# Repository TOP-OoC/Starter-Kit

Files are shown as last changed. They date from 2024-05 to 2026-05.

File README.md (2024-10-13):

# Starter-Kit

## Description
The TOP Starter Kit is an open-source, reconfigurable platform for Organ on Chip (OoC) research. It implements a Fluidic Circuit Board (FCB) architecture, meaning that Microfluidic Building Blocks (MFBBs) are the functional units and fluids are routed between MFBBs via a single manifold, the FCB.

The specific FCB used in the Stater Kit is designed to allow arbitrary connections between microfluidic modules. Interconnections can be easily changed to whatever the user desires by simply exchanging a single MFBB called the Routing Block. 

Microfluidic building block port layouts and footprints follow our [TOP Design Rules (TDRs)](https://data.4tu.nl/datasets/2558bd4c-d7ad-4e17-bc54-8c335b4c1c01) which are compliant with [ISO 22916:2022](https://www.iso.org/standard/74157.html) (See also: [a short introduction to ISO:22916:2022](https://data.4tu.nl/datasets/871d6c3a-cf1a-44f9-865a-6da842bd2f27/2)).

Taking all of it's features together, the TOP Starter Kit allows a powerful simplification of the broader OoC design space: A chip designer needs only to adhere to the TDRs to ensure that their device can be immediately used in a wide range of different fit-to-purpose fluidic circuits without ever needing to design a custom FCB.

## Content
- [Fluidic Circuit Board (FCB)](https://github.com/TOP-OoC/Starter-Kit/blob/main/FCB/)
- [Reservoirs](https://github.com/TOP-OoC/Starter-Kit/tree/main/Reservoirs)
- [Pump Module](https://github.com/TOP-OoC/Starter-Kit/tree/main/Pump_Module)
- More to come...

## Contact
For more information contact:
- Joshua Loessberg-Zahl (j.t.loessberg-zahl@utwente.nl)

## Under Development:
- Annotated Schamatics
- Fabrication Requirements
- SOPs
- Typical Microfluidic Building Blocks

___

[][cc-by]

This work is licensed under a
[Creative Commons Attribution 4.0 International License][cc-by].

[][cc-by]

[cc-by]: http://creativecommons.org/licenses/by/4.0/
[cc-by-image]: https://i.creativecommons.org/l/by/4.0/88x31.png
[cc-by-shield]: https://img.shields.io/badge/License-CC%20BY%204.0-lightgrey.svg

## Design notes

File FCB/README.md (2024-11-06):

# Starter Kit FCB

## Description
STL files for the Starter Kit FCB

## Credits

### Designer Credits:
Aniruddha Paul

Eric Safai

Joshua Loessberg-Zahl

### Manufacturing Credits:
The Fluidic Circuit Boards with this design used at University of Twente were manufactured both in-house and by Micronit (www.micronit.com). Sandro Meucci and Fabien Abeille were our contacts at Micronit for manufacturing.

### Extra Credits:
The design work was done at University of Twente in the Netherlands, supported by the university’s Organ-on-Chip Centre Twente (www.utwente.nl/oocct), specifically at the groups: Applied Stem Cell Technologies and BIOS Lab-on-a-Chip Group. 

The work was funded by SMART OoC, an NWO-TTW Perspective Programme of the Dutch Research Council (NWO; project number P19-03), and the Netherlands Organ-on-Chip Initiative, an NWO Gravitation project (024.003.001) by the Ministry of Education, Culture and Science of the government of the Netherlands.

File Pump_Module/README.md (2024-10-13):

# Starter Kit Pump Module

## Description
STL files, original sldprt files, PCB design files, and firmware for the Starter Kit Pump Module

This module uses six stepper-motor driven peristaltic pumps, manufactured by Takasago Fluidic Systems.  Specifically: [Stepper Motor Type of Ring Pump RP-QⅡ/RP-QⅢ Series [Discharge Rate: 0.18 ~ 180 μL/min]](https://www.takasago-fluidics.com/products/rp-q-stepper-2?variant=45644386238630)

A custom, small form factor, pump driver PCB is also included here. An Arduino Nano 33 IoT must be soldered onto this driver to control the module. 

Six unpopulated spaces for through-hole resistors are left in the PCB for pump-specific feedback resistors to be added.  These resistors control the current output by the driver and must be added during or after manufacturing.  For the pumps listed here, a resistor value of 56 kOhm was used.

The provided firmware for the pump driver PCB allows individual control of the pumps via BLE.

Design files for a PMMA Pump Block Base that makes fluidic contact between the pumps and the FCB are also included.

The PCB is connected to the Pump Block Base with M2 PCB standoffs.

A photo of the assembled module is shown below to assist with assembly. Note that the PCB is conformal coated with epoxy before use in high humidity settings.

PumpModulePicture

## Credits

### Designer Credits:
Aniruddha Paul
Eric Safai
Joshua Loessberg-Zahl

### Manufacturing Credits:
This design was manufactured in-house at University of Twente.  PCB manufacturing was outsourced to both JLCPCB and Eurocircuits.

### Extra Credits:
The design work was done at University of Twente in the Netherlands, supported by the university’s Organ-on-Chip Centre Twente (www.utwente.nl/oocct), specifically at the groups: Applied Stem Cell Technologies and BIOS Lab-on-a-Chip Group. 

The work was funded by SMART OoC, an NWO-TTW Perspective Programme of the Dutch Research Council (NWO; project number P19-03), and the Netherlands Organ-on-Chip Initiative, an NWO Gravitation project (024.003.001) by the Ministry of Education, Culture and Science of the government of the Netherlands.

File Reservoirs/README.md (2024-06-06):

# Reservoirs

## Description
A selection of reservoirs that conform to the [TDRs](https://data.4tu.nl/datasets/2558bd4c-d7ad-4e17-bc54-8c335b4c1c01).

## Contents

## Under Construction
- Schematics
- Descriptions of intended use
- Manufacturing SOPs
- Operational SOPs

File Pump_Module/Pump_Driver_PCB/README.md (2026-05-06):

# Description
Design files and firmware for the pump module driver PCB

## Arduino Firmware Version
Please ensure that the Arduino firmware itself has been updated to at least 3.0.1 for correct functioning of the BLE connection. See [this](https://blog.arduino.cc/2026/03/02/you-can-now-use-wi-fi-and-bluetooth-le-simultaneously-on-arduino-nina-based-boards-heres-how/) article for reference.

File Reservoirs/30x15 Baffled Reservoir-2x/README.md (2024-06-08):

# Description

Baffled Reservoir-2x

A reservoir Microfluidic Building Block (MFBB) with 4 ports that fits in a 30x15 footprint.

The MFBB is used to convert an incomming flow into a lower, fixed-pressure flow.

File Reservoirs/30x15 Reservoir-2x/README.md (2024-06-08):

# Description

30x15 Reservoir-3x

A reservoir Microfluidic Building Block (MFBB) with 4 ports that fits in a 30x15 footprint.

The MFBB has 2 parallel reservoirs, each with 2 ports.

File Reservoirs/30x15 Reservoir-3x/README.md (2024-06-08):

# Description
30x15 Reservoir-3x

A reservoir Microfluidic Building Block (MFBB) with 6 ports that fits in a 30x15 footprint.

The MFBB has 3 parallel reservoirs, each with 2 ports.

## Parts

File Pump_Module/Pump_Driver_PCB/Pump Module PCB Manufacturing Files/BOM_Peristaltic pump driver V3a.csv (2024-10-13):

Qty | Value | Device | Package | Parts | Description | PROD_ID
12 | 0.1R | R-EU_R0603 | R0603 | RS1, RS2, RS3, RS4, RS5, RS6, RS7, RS8, RS9, RS10, RS11, RS12 | RESISTOR, European symbol
6 | 0R | R-EU_R0603 | R0603 | R6, R9, R14, R19, R24, R29 | RESISTOR, European symbol
12 | 100K | R-EU_R0603 | R0603 | R1, R4, R8, R10, R13, R15, R18, R20, R23, R25, R28, R30 | RESISTOR, European symbol
30 | 100n | C-EUC0603 | C0603 | C1, C3, C4, C5, C7, C9, C10, C11, C13, C14, C15, C16, C17, C19, C20, C21, C22, C23, C25, C26, C27, C28, C29, C31, C32, C33, C34, C35, C37, C38 | CAPACITOR, European symbol
6 | 220n | C-EUC0603 | C0603 | C6, C12, C18, C24, C30, C36 | CAPACITOR, European symbol
6 | 2K | R-EU_R0603 | R0603 | R3, R7, R12, R17, R22, R27 | RESISTOR, European symbol
6 | 82K | R-EU_R0603 | R0603 | R2, R5, R11, R16, R21, R26 | RESISTOR, European symbol
6 | A4988 | A4988-QFN28 | QFN28 | DRV1, DRV2, DRV3, DRV4, DRV5, DRV6 | Flash Microcontrollers

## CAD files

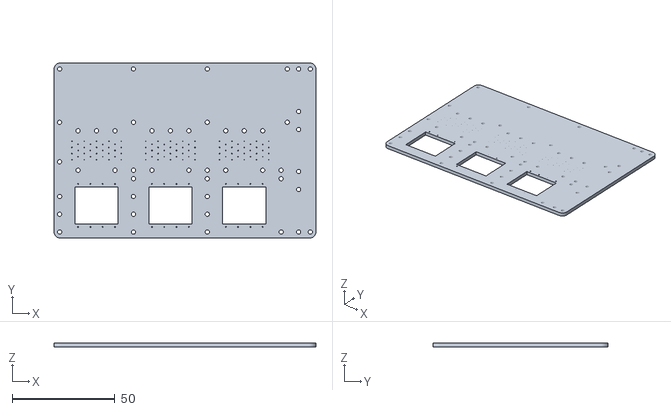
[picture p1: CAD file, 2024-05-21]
FCB/Starter Docking Plate Bottom layer.STL
127.7 x 85.5 x 2.00

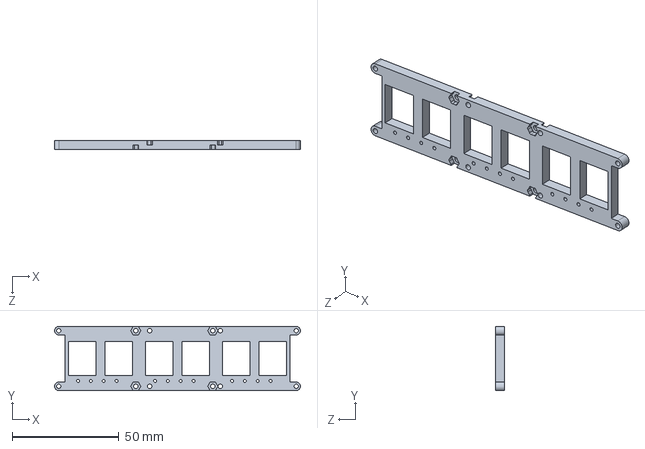
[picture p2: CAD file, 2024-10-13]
Pump_Module/PumpBlockBase.SLDPRT
115.0 x 30.0 x 4.00 mm

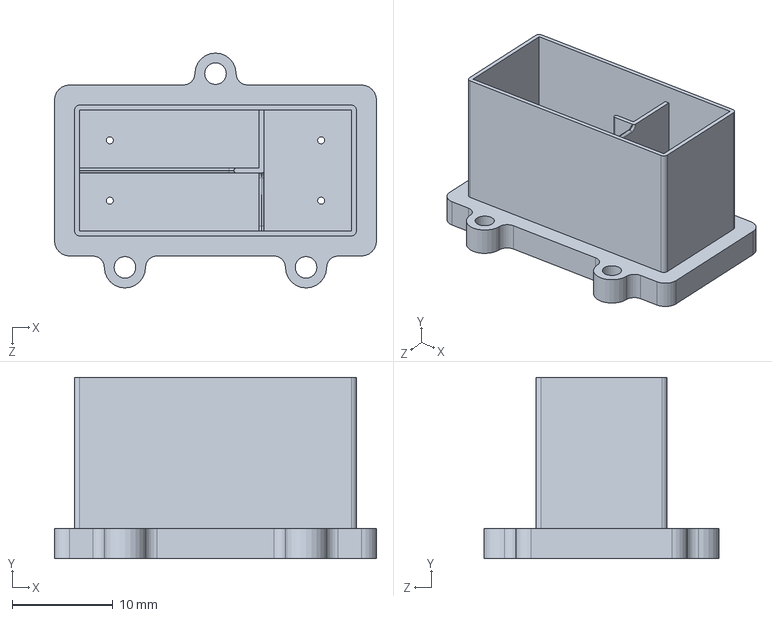
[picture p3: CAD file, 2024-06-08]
Reservoirs/30x15 Baffled Reservoir-2x/30x15 Baffled Reservoir-2x_v1.03.SLDPRT
32.0 x 18.0 x 23.4 mm

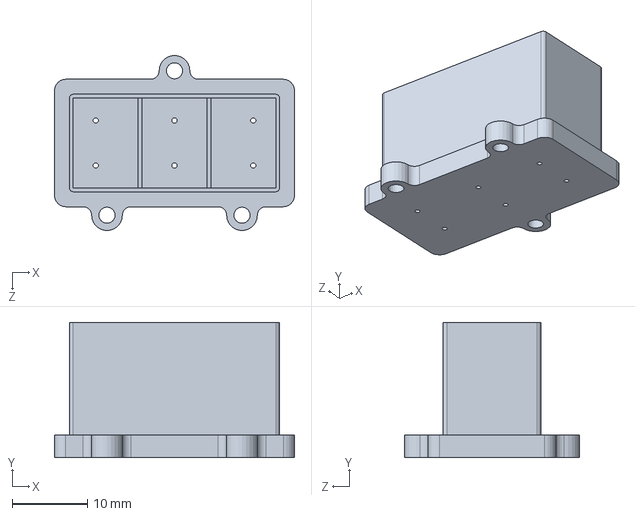
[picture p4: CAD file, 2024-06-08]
Reservoirs/30x15 Reservoir-3x/30x15 Reservoir-3x_v1.03.SLDPRT
32.0 x 18.0 x 23.4 mm

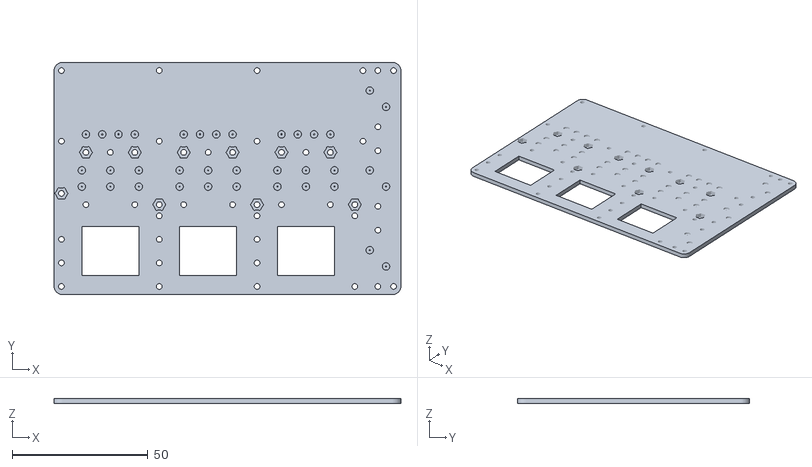
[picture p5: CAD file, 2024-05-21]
FCB/Starter Docking Plate Top layer.STL
127.7 x 85.5 x 2.00

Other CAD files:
Reservoirs/30x15 Reservoir-2x/30x15 Reservoir-2x_v1.01.SLDPRT
Pump_Module/PumpBlockBase.STL
Reservoirs/30x15 Baffled Reservoir-2x/30x15 Baffled Reservoir-2x_v1.03.STL
Reservoirs/30x15 Reservoir-2x/30x15 Reservoir-2x_v1.01.STL
Reservoirs/30x15 Reservoir-3x/30x15 Reservoir-3x_v1.03.STL

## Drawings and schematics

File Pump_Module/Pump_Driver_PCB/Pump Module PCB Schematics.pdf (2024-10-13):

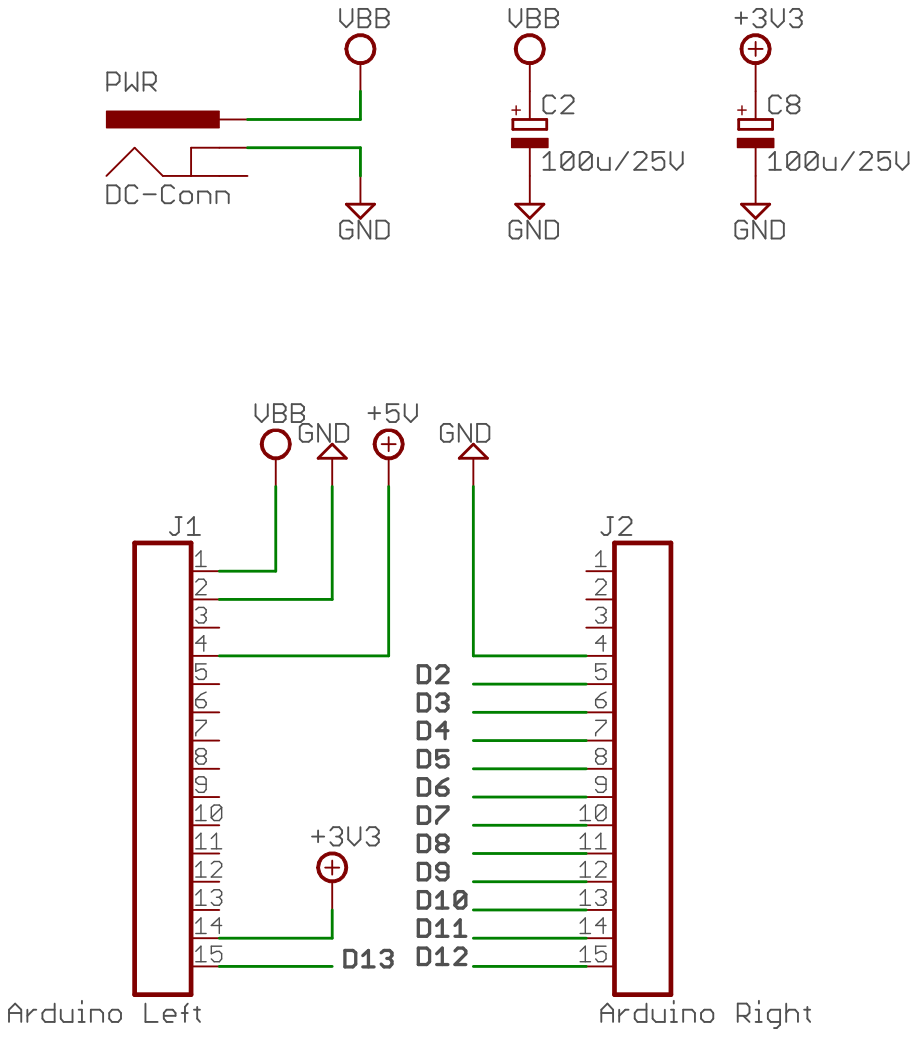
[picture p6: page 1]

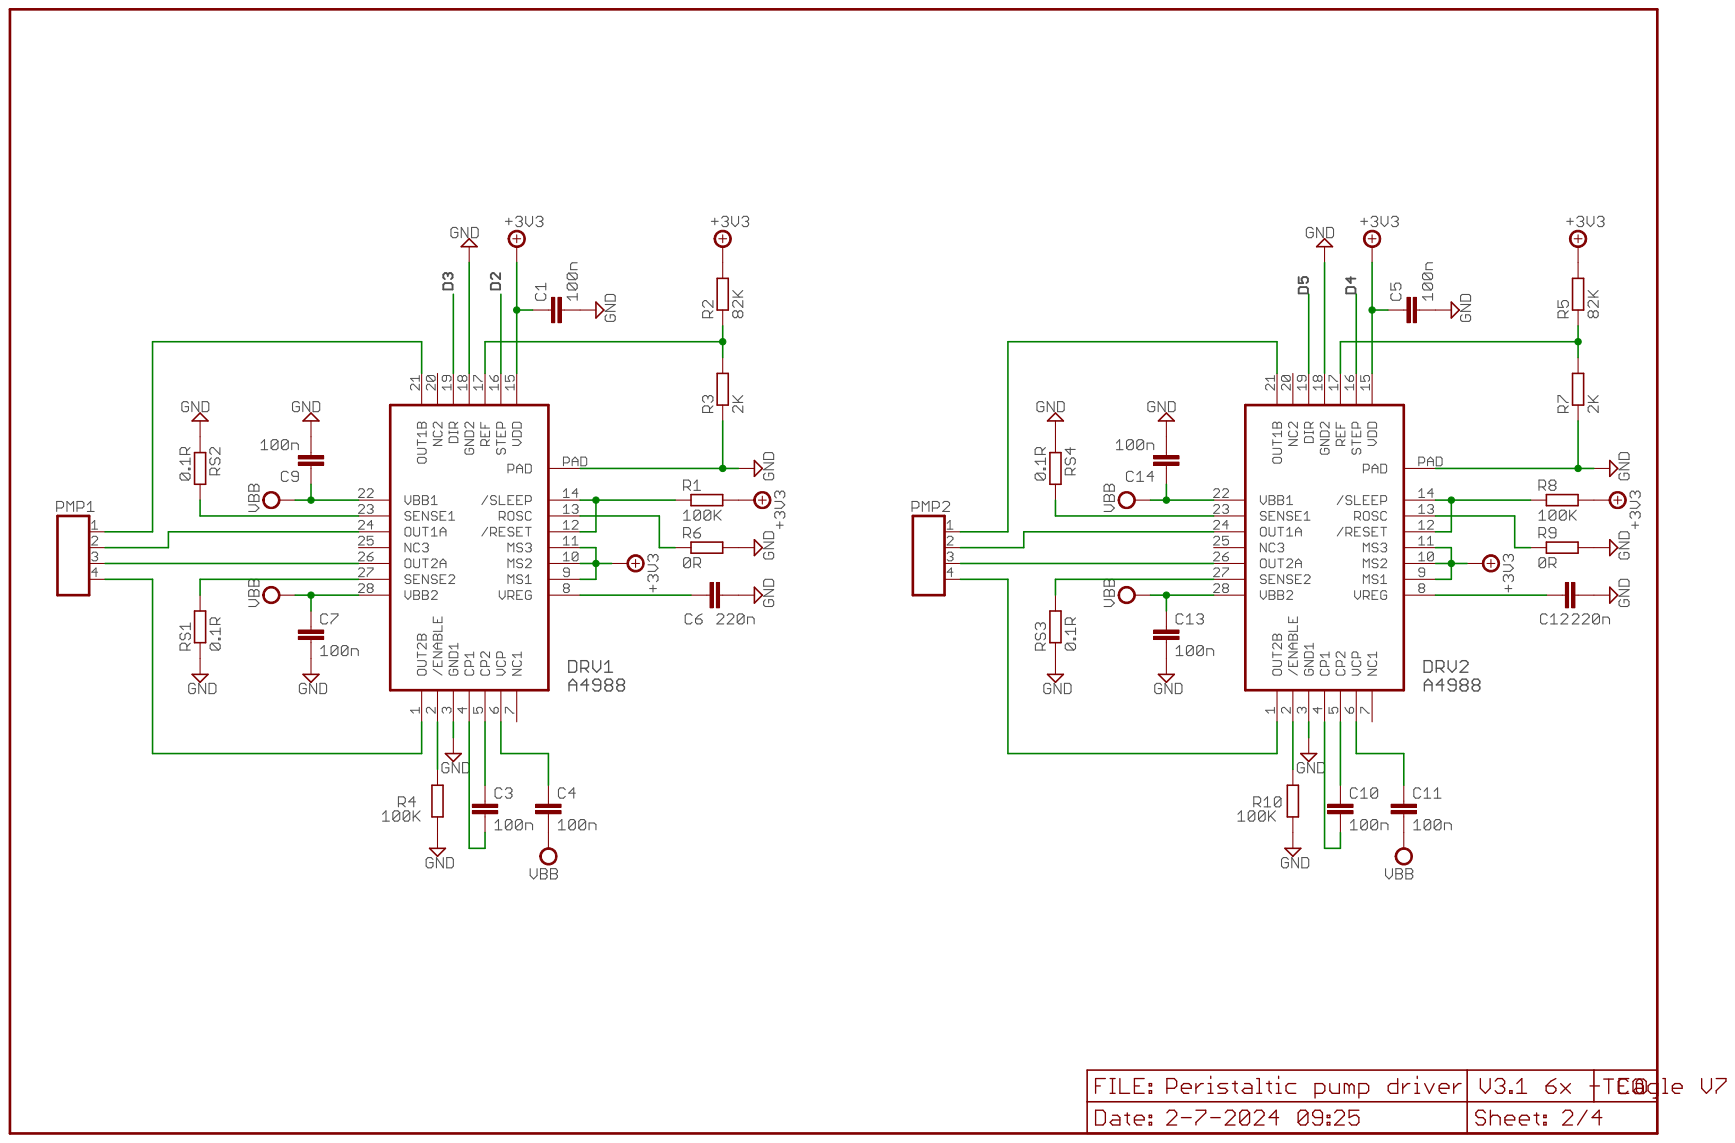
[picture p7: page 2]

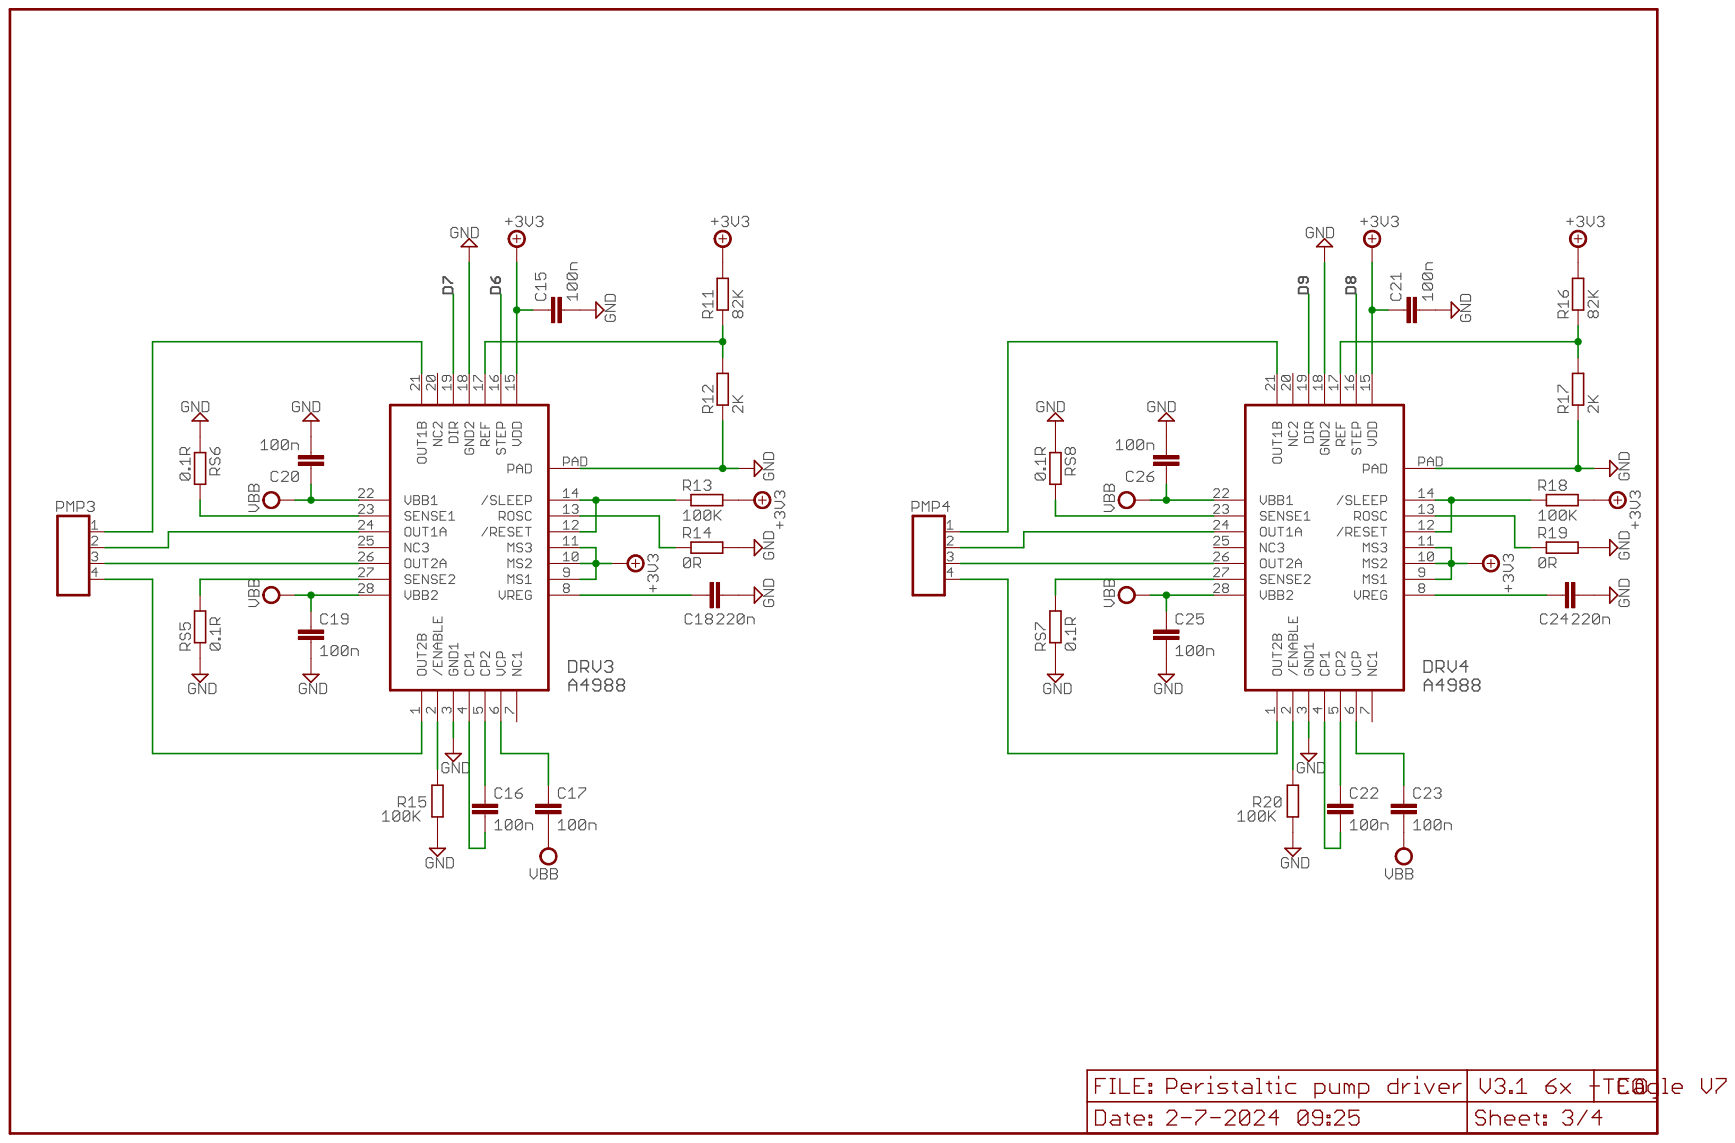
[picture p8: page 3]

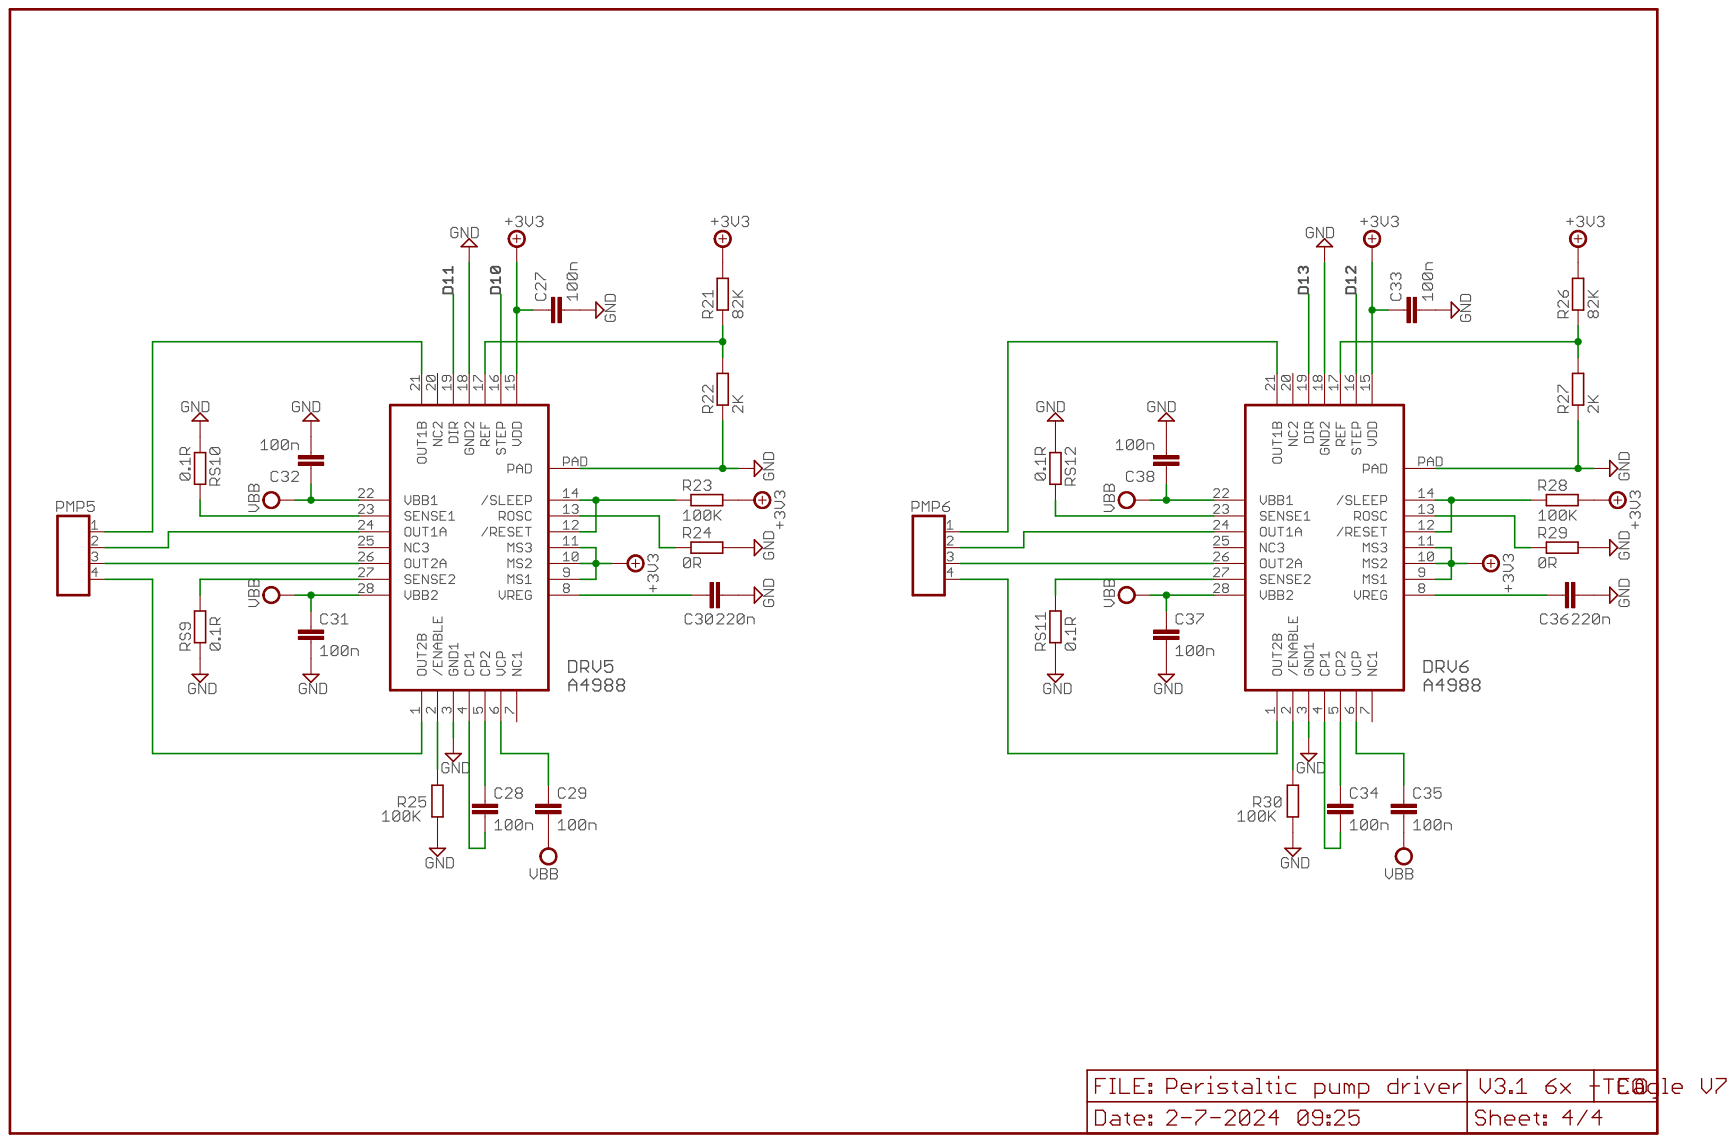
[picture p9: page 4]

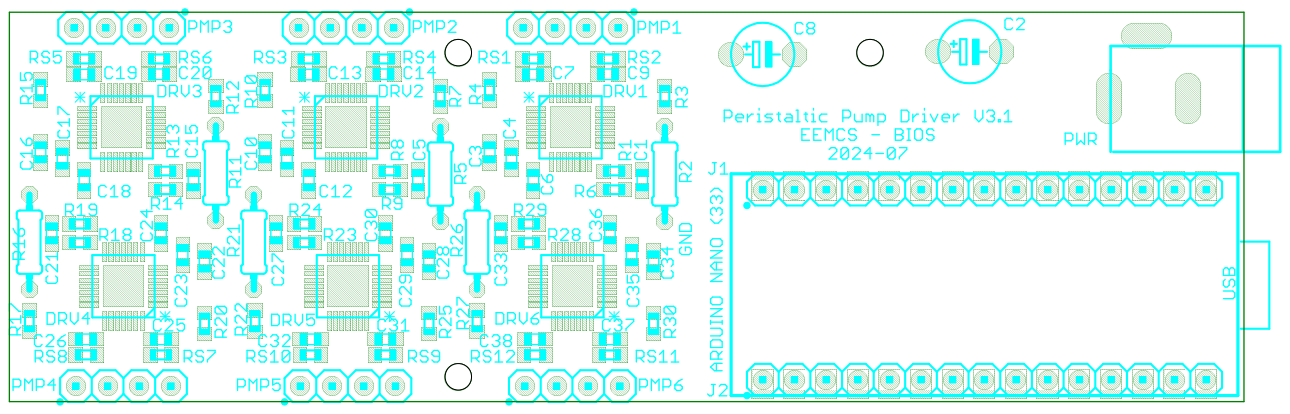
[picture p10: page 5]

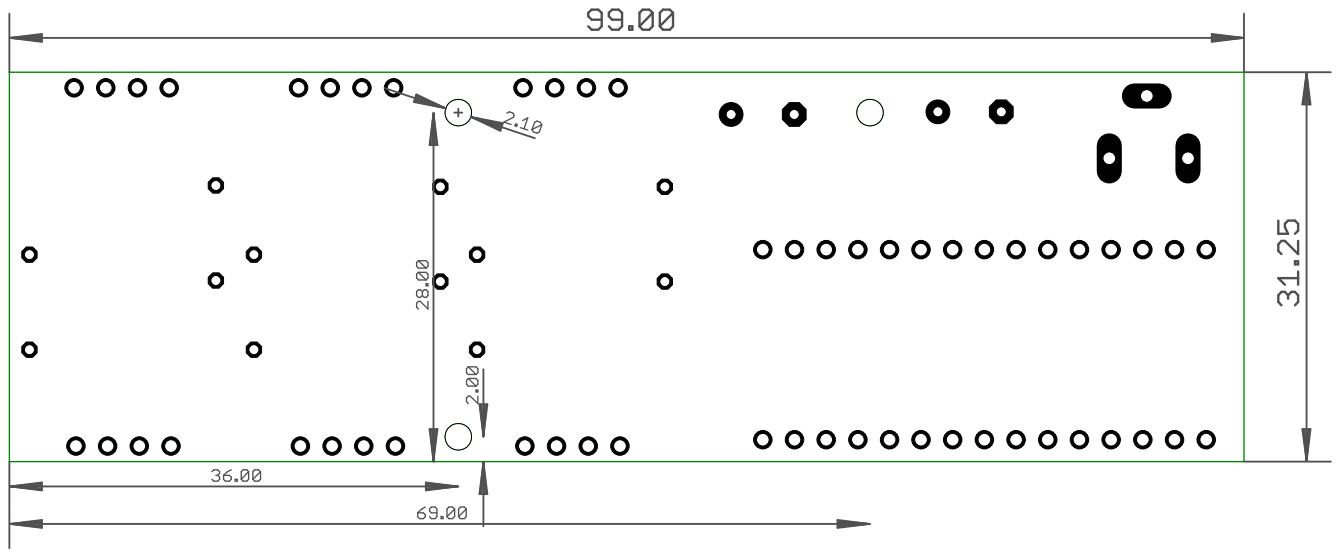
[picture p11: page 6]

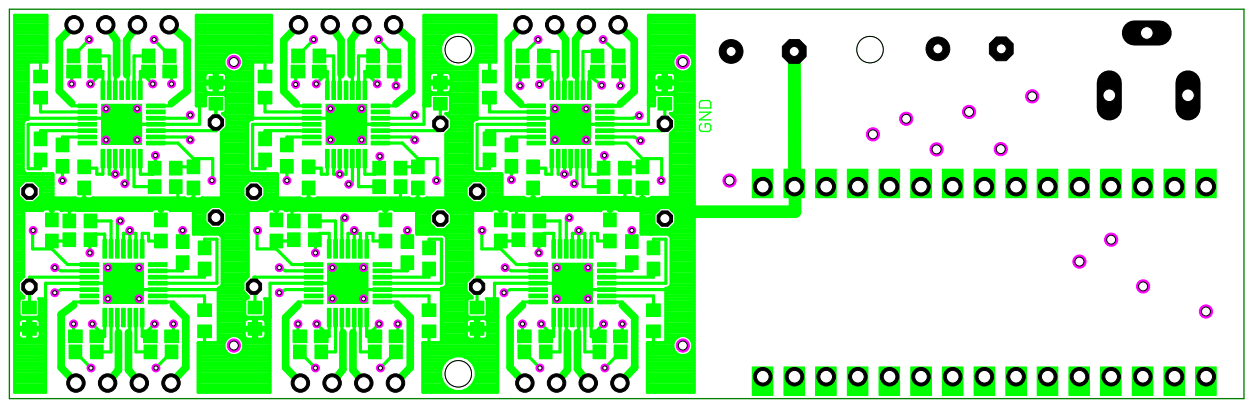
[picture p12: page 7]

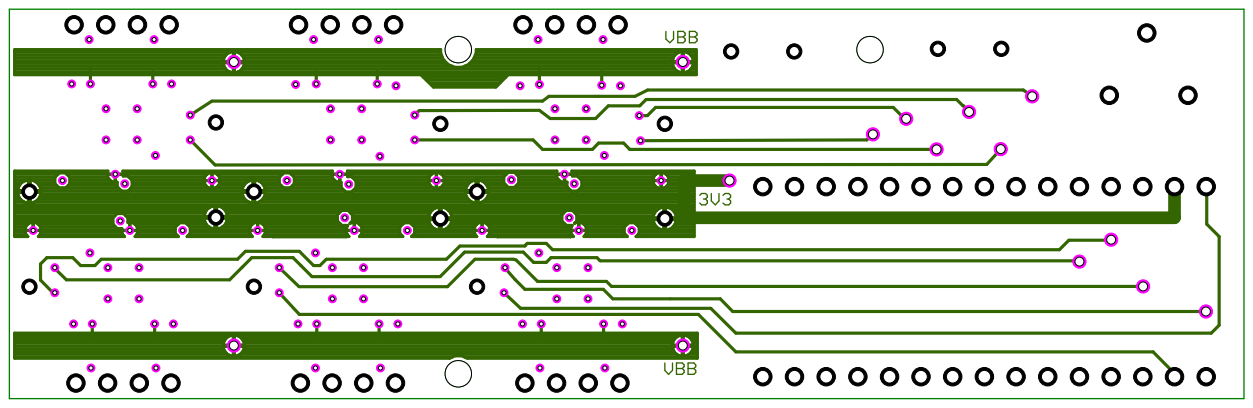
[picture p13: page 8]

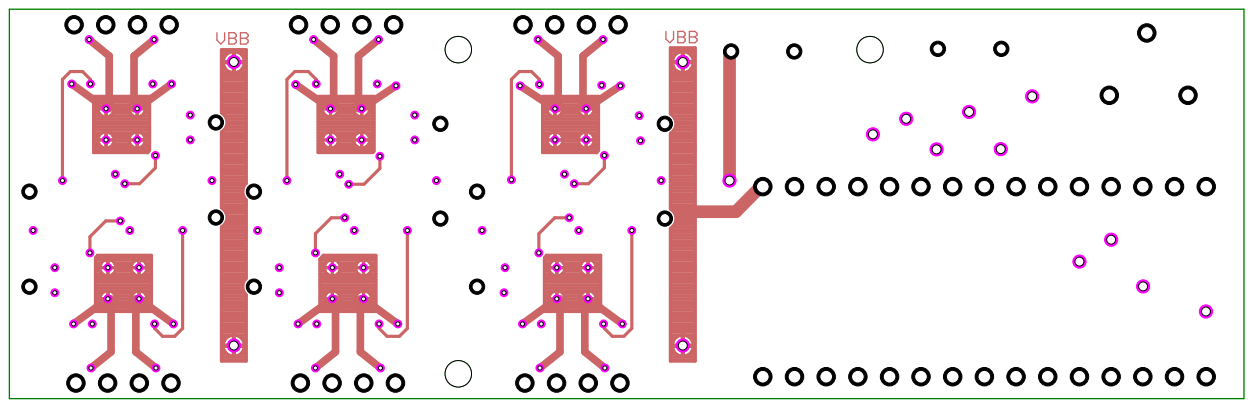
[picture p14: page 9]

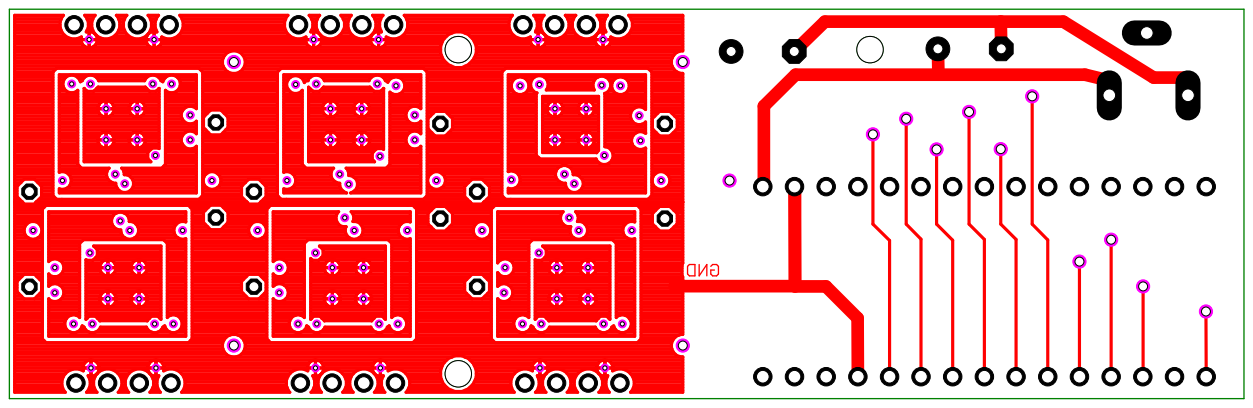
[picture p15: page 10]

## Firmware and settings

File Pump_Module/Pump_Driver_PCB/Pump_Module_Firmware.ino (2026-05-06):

#include <ArduinoBLE.h>
#include <FlashStorage.h>

//board name
const char board_name[] = "PumpModule_0003";

//permanent variables
FlashStorage(not_first_boot, bool);
FlashStorage(pump_1_freq, int);
FlashStorage(pump_2_freq, int);
FlashStorage(pump_3_freq, int);
FlashStorage(pump_4_freq, int);
FlashStorage(pump_5_freq, int);
FlashStorage(pump_6_freq, int);

//Pins
const int DIR_PIN_1 = 3;
const int STEP_PIN_1 = 2;
const int DIR_PIN_2 = 5;
const int STEP_PIN_2 = 4;
const int DIR_PIN_3 = 7;
const int STEP_PIN_3 = 6;
const int DIR_PIN_4 = 9;
const int STEP_PIN_4 = 8;
const int DIR_PIN_5 = 11;
const int STEP_PIN_5 = 10;
const int DIR_PIN_6 = 13;
const int STEP_PIN_6 = 12;

//Timer Constants
const int DELAY_TIME_BLE = 100000;

//intital values
int init_pump_freq = 0; //set to 0 KHz to start

//timers for each pump
int delay_time_1 = 0;    //microseconds time to delay
unsigned long last_time_1 = 0; // time of the next switch
int delay_time_2 = 0;
unsigned long last_time_2 = 0;
int delay_time_3 = 0;
unsigned long last_time_3 = 0;
int delay_time_4 = 0;
unsigned long last_time_4 = 0;
int delay_time_5 = 0;
unsigned long last_time_5 = 0;
int delay_time_6 = 0;
unsigned long last_time_6 = 0;
unsigned long last_time_BLE = 0; //timer for checking for ble updates

//Universal timer
unsigned long current_time = 0; //stores the last measured time (in uSeconds)

//Pump states
bool pump_1_step = LOW; //State of the first pump step pin
bool pump_2_step = LOW;
bool pump_3_step = LOW;
bool pump_4_step = LOW;
bool pump_5_step = LOW;
bool pump_6_step = LOW;

bool pump_1_active = LOW; //if the first pump is on
bool pump_2_active = LOW;
bool pump_3_active = LOW;
bool pump_4_active = LOW;
bool pump_5_active = LOW;
bool pump_6_active = LOW;

BLEService pumpService("180A"); // BLE pump Service

// BLE characteristics for controlling pump
BLEIntCharacteristic Pump1Characteristic("2A57", BLERead | BLEWrite);
BLEDescriptor Pump1CharacteristicDescriptor("2901", "Pump 1 Frequency (int | Hz)");
BLEIntCharacteristic Pump2Characteristic("2A57", BLERead | BLEWrite);
BLEDescriptor Pump2CharacteristicDescriptor("2901", "Pump 2 Frequency (int | Hz)");
BLEIntCharacteristic Pump3Characteristic("2A57", BLERead | BLEWrite);
BLEDescriptor Pump3CharacteristicDescriptor("2901", "Pump 3 Frequency (int | Hz)");
BLEIntCharacteristic Pump4Characteristic("2A57", BLERead | BLEWrite);
BLEDescriptor Pump4CharacteristicDescriptor("2901", "Pump 4 Frequency (int | Hz)");
BLEIntCharacteristic Pump5Characteristic("2A57", BLERead | BLEWrite);
BLEDescriptor Pump5CharacteristicDescriptor("2901", "Pump 5 Frequency (int | Hz)");
BLEIntCharacteristic Pump6Characteristic("2A57", BLERead | BLEWrite);
BLEDescriptor Pump6CharacteristicDescriptor("2901", "Pump 6 Frequency (int | Hz)");

//BLE connected flag and associated callbacks
volatile bool ble_connected = false;

void bleConnectHandler(BLEDevice central) {
  ble_connected = true;
  //Serial.print("Connected: ");
  //Serial.println(central.address());
}

void bleDisconnectHandler(BLEDevice central) {
  ble_connected = false;
  //Serial.print("Disconnected: ");
  //Serial.println(central.address());
}

void setup() {
  //Variable for reading the pump direction to later update the initail value of the BLE characteristics
  int pump_1_dir = -1;
  int pump_2_dir = -1;
  int pump_3_dir = -1;
  int pump_4_dir = -1;
  int pump_5_dir = -1;
  int pump_6_dir = -1;
  
  Serial.begin(9600);
  //while (!Serial);

  // setup output pins
  delayMicroseconds(1000);
  
  pinMode(DIR_PIN_1, OUTPUT);
  pinMode(STEP_PIN_1, OUTPUT);
  digitalWrite(DIR_PIN_1, LOW);
  digitalWrite(STEP_PIN_1, LOW);
  pinMode(DIR_PIN_2, OUTPUT);
  pinMode(STEP_PIN_2, OUTPUT);
  digitalWrite(DIR_PIN_2, LOW);
  digitalWrite(STEP_PIN_2, LOW);
  pinMode(DIR_PIN_3, OUTPUT);
  pinMode(STEP_PIN_3, OUTPUT);
  digitalWrite(DIR_PIN_3, LOW);
  digitalWrite(STEP_PIN_3, LOW);
  pinMode(DIR_PIN_4, OUTPUT);
  pinMode(STEP_PIN_4, OUTPUT);
  digitalWrite(DIR_PIN_4, LOW);
  digitalWrite(STEP_PIN_4, LOW);
  pinMode(DIR_PIN_5, OUTPUT);
  pinMode(STEP_PIN_5, OUTPUT);
  digitalWrite(DIR_PIN_5, LOW);
  digitalWrite(STEP_PIN_5, LOW);
  pinMode(DIR_PIN_6, OUTPUT);
  pinMode(STEP_PIN_6, OUTPUT);
  digitalWrite(DIR_PIN_6, LOW);
  digitalWrite(STEP_PIN_6, LOW);

  //initialize flash on first boot (when new firmware is flashed all flash variables are set to 0)
  if (!not_first_boot.read()) {     
    not_first_boot.write(1);
    pump_1_freq.write(init_pump_freq);
    pump_2_freq.write(init_pump_freq);
    pump_3_freq.write(init_pump_freq);
    pump_4_freq.write(init_pump_freq);
    pump_5_freq.write(init_pump_freq);
    pump_6_freq.write(init_pump_freq);
  }

  //Setup state of all pumps based on flash memory
  //Pump 1
  int read_value = pump_1_freq.read(); //read the value from memory, then parse read_value                        
  if (read_value < 0){     //set pump to active, flip sign of read value, and set DIR pin to low
    pump_1_active = HIGH;
    digitalWrite(DIR_PIN_1, LOW);
    pump_1_dir = -1;
    delay_time_1 = (unsigned long)((float)1000000/(-(float)read_value));
  }
  else if (read_value == 0) {  //set dir pin high, pump to inactive and speed to 1Hz(speed will be ignored later)
    pump_1_active = LOW;
    digitalWrite(DIR_PIN_1, HIGH);
    pump_1_dir = 1;
    delay_time_1 = (unsigned long)(1000000);
  }
  else{                       //otherwise set pump to active, dir pin to high, and delay time normally
    pump_1_active = HIGH;
    digitalWrite(DIR_PIN_1, HIGH);
    pump_1_dir = 1;
    delay_time_1 = (unsigned long)((float)1000000/(float)read_value);
  }
  
  //Pump2
  read_value = pump_2_freq.read(); //read the value from memory, then parse read_value                        
  if (read_value < 0){     //set pump to active, flip sign of read value, and set DIR pin to low
    pump_2_active = HIGH;
    digitalWrite(DIR_PIN_2, LOW);
    pump_2_dir = -1;
    delay_time_2 = (unsigned long)((float)1000000/(-(float)read_value));
  }
  else if (read_value == 0) {  //set dir pin high, pump to inactive and speed to 1Hz(speed will be ignored later)
    pump_2_active = LOW;
    digitalWrite(DIR_PIN_2, HIGH);
    pump_2_dir = 1;
    delay_time_2 = (unsigned long)(1000000);
  }
  else{                       //otherwise set pump to active, dir pin to high, and delay time normally
    pump_2_active = HIGH;
    digitalWrite(DIR_PIN_2, HIGH);
    pump_2_dir = 1;
    delay_time_2 = (unsigned long)((float)1000000/(float)read_value);
  }

  //Pump3
  read_value = pump_3_freq.read(); //read the value from memory, then parse read_value                        
  if (read_value < 0){     //set pump to active, flip sign of read value, and set DIR pin to low
    pump_3_active = HIGH;
    digitalWrite(DIR_PIN_3, LOW);
    pump_3_dir = -1;
    delay_time_3 = (unsigned long)((float)1000000/(-(float)read_value));
  }
  else if (read_value == 0) {  //set dir pin high, pump to inactive and speed to 1Hz(speed will be ignored later)
    pump_3_active = LOW;
    digitalWrite(DIR_PIN_3, HIGH);
    pump_3_dir = 1;
    delay_time_3 = (unsigned long)(1000000);
  }
  else{                       //otherwise set pump to active, dir pin to high, and delay time normally
    pump_3_active = HIGH;
    digitalWrite(DIR_PIN_3, HIGH);
    pump_3_dir = 1;
    delay_time_3 = (unsigned long)((float)1000000/(float)read_value);
  }

  //Pump4
  read_value = pump_4_freq.read(); //read the value from memory, then parse read_value                        
  if (read_value < 0){     //set pump to active, flip sign of read value, and set DIR pin to low
    pump_4_active = HIGH;
    digitalWrite(DIR_PIN_4, LOW);
    pump_4_dir = -1;
    delay_time_4 = (unsigned long)((float)1000000/(-(float)read_value));
  }
  else if (read_value == 0) {  //set dir pin high, pump to inactive and speed to 1Hz(speed will be ignored later)
    pump_4_active = LOW;
    digitalWrite(DIR_PIN_4, HIGH);
    pump_4_dir = 1;
    delay_time_4 = (unsigned long)(1000000);
  }
  else{                       //otherwise set pump to active, dir pin to high, and delay time normally
    pump_4_active = HIGH;
    digitalWrite(DIR_PIN_4, HIGH);
    pump_4_dir = 1;
    delay_time_4 = (unsigned long)((float)1000000/(float)read_value);
  }

  //Pump5
  read_value = pump_5_freq.read(); //read the value from memory, then parse read_value                        
  if (read_value < 0){     //set pump to active, flip sign of read value, and set DIR pin to low
    pump_5_active = HIGH;
    digitalWrite(DIR_PIN_5, LOW);
    pump_5_dir = -1;
    delay_time_5 = (unsigned long)((float)1000000/(-(float)read_value));
  }
  else if (read_value == 0) {  //set dir pin high, pump to inactive and speed to 1Hz(speed will be ignored later)
    pump_5_active = LOW;
    digitalWrite(DIR_PIN_5, HIGH);
    pump_5_dir = 1;
    delay_time_5 = (unsigned long)(1000000);
  }
  else{                       //otherwise set pump to active, dir pin to high, and delay time normally
    pump_5_active = HIGH;
    digitalWrite(DIR_PIN_5, HIGH);
    pump_5_dir = 1;
    delay_time_5 = (unsigned long)((float)1000000/(float)read_value);
  }

  //Pump6
  read_value = pump_6_freq.read(); //read the value from memory, then parse read_value                        
  if (read_value < 0){     //set pump to active, flip sign of read value, and set DIR pin to low
    pump_6_active = HIGH;
    digitalWrite(DIR_PIN_6, LOW);
    pump_6_dir = -1;
    delay_time_6 = (unsigned long)((float)1000000/(-(float)read_value));
  }
  else if (read_value == 0) {  //set dir pin high, pump to inactive and speed to 1Hz(speed will be ignored later)
    pump_6_active = LOW;
    digitalWrite(DIR_PIN_6, HIGH);
    pump_6_dir = 1;
    delay_time_6 = (unsigned long)(1000000);
  }
  else{                       //otherwise set pump to active, dir pin to high, and delay time normally
    pump_6_active = HIGH;
    digitalWrite(DIR_PIN_6, HIGH);
    pump_6_dir = 1;
    delay_time_6 = (unsigned long)((float)1000000/(float)read_value);
  }

  // begin initialization
  if (!BLE.begin()) {
    Serial.println("starting Bluetooth® Low Energy failed!");
    while (1);
  }

  // set advertised local name and service UUID:
  BLE.setLocalName(board_name);
  BLE.setAdvertisedService(pumpService);

  //Add descriptors to characteristics
  Pump1Characteristic.addDescriptor(Pump1CharacteristicDescriptor);
  Pump2Characteristic.addDescriptor(Pump2CharacteristicDescriptor);
  Pump3Characteristic.addDescriptor(Pump3CharacteristicDescriptor);
  Pump4Characteristic.addDescriptor(Pump4CharacteristicDescriptor);
  Pump5Characteristic.addDescriptor(Pump5CharacteristicDescriptor);
  Pump6Characteristic.addDescriptor(Pump6CharacteristicDescriptor);
    
  // add the characteristic to the service
  pumpService.addCharacteristic(Pump1Characteristic);
  pumpService.addCharacteristic(Pump2Characteristic);
  pumpService.addCharacteristic(Pump3Characteristic);
  pumpService.addCharacteristic(Pump4Characteristic);
  pumpService.addCharacteristic(Pump5Characteristic);
  pumpService.addCharacteristic(Pump6Characteristic);

  // add service
  BLE.addService(pumpService);

  // set the initial value for the characteristic (note that this is based on the flash memory which has set delay_time):
  Pump1Characteristic.writeValue((int)(pump_1_dir*(float)1000000/(float)delay_time_1)*(int)pump_1_active);
  Pump2Characteristic.writeValue((int)(pump_2_dir*(float)1000000/(float)delay_time_2)*(int)pump_2_active);
  Pump3Characteristic.writeValue((int)(pump_3_dir*(float)1000000/(float)delay_time_3)*(int)pump_3_active);
  Pump4Characteristic.writeValue((int)(pump_4_dir*(float)1000000/(float)delay_time_4)*(int)pump_4_active);
  Pump5Characteristic.writeValue((int)(pump_5_dir*(float)1000000/(float)delay_time_5)*(int)pump_5_active);
  Pump6Characteristic.writeValue((int)(pump_6_dir*(float)1000000/(float)delay_time_6)*(int)pump_6_active);

  //Setup callbacks to report if a user is connected or not
  BLE.setEventHandler(BLEConnected, bleConnectHandler);
  BLE.setEventHandler(BLEDisconnected, bleDisconnectHandler);

  // start advertising
  BLE.advertise();

  //start timers
  current_time = micros();
  last_time_1 = current_time;
  last_time_2 = current_time;
  last_time_3 = current_time;
  last_time_4 = current_time;
  last_time_5 = current_time;
  last_time_6 = current_time;
  last_time_BLE = current_time;

  Serial.println("Pump Module Online");
}

void loop() {

  current_time = micros();

  if (current_time - last_time_BLE >= DELAY_TIME_BLE){
    last_time_BLE = current_time;
    BLE.poll(0);

    if(ble_connected){
      // listen for BLE peripherals to connect:
      BLEDevice central = BLE.central();

      // if a central is connected to peripheral:
      if (central) {
        if (central.connected()) {
          // if the remote device wrote to the characteristic,
          // use the value to set control values for pumps:
          
          if (Pump1Characteristic.written()) {
            int read_value = Pump1Characteristic.value();
            pump_1_freq.write(read_value);
            Serial.println(String(read_value));

            //parse read_value
            if (read_value < 0){     //set pump to active, flip sign of read value, and set DIR pin to low
              pump_1_active = HIGH;
              digitalWrite(DIR_PIN_1, LOW);
              delay_time_1 = (unsigned long)((float)1000000/(-(float)read_value));
            }
            else if (read_value == 0) {  //set dir pin high, pump to inactive and speed to 1Hz(speed will be ignored later)
              pump_1_active = LOW;
              digitalWrite(DIR_PIN_1, HIGH);
              delay_time_1 = (unsigned long)(1000000);
            }
            else{                       //otherwise set pump to active, dir pin to high, and delay time normally
              pump_1_active = HIGH;
              digitalWrite(DIR_PIN_1, HIGH);
              delay_time_1 = (unsigned long)((float)1000000/(float)read_value);
            }

            Serial.println(String(delay_time_1));
            last_time_1 = micros(); //puts next step time into the future
            Serial.println("value updated!");
          }
          
          if (Pump2Characteristic.written()) {
            int read_value = Pump2Characteristic.value();
            pump_2_freq.write(read_value);

            //parse read_value
            if (read_value < 0){     //set pump to active, flip sign of read value, and set DIR pin to low
              pump_2_active = HIGH;
              digitalWrite(DIR_PIN_2, LOW);
              delay_time_2 = (unsigned long)((float)1000000/(-(float)read_value));
            }
            else if (read_value == 0) {  //set dir pin high, pump to inactive and speed to 1Hz(speed will be ignored later)
              pump_2_active = LOW;
              digitalWrite(DIR_PIN_2, HIGH);
              delay_time_2 = (unsigned long)(1000000);
            }
            else{                       //otherwise set pump to active, dir pin to high, and delay time normally
              pump_2_active = HIGH;
              digitalWrite(DIR_PIN_2, HIGH);
              delay_time_2 = (unsigned long)((float)1000000/(float)read_value);
            }
            
            last_time_2 = micros(); //puts next step time into the future
            Serial.println("value updated!");
          }

          if (Pump3Characteristic.written()) {
            int read_value = Pump3Characteristic.value();
            pump_3_freq.write(read_value);

            //parse read_value
            if (read_value < 0){     //set pump to active, flip sign of read value, and set DIR pin to low
              pump_3_active = HIGH;
              digitalWrite(DIR_PIN_3, LOW);
              delay_time_3 = (unsigned long)((float)1000000/(-(float)read_value));
            }
            else if (read_value == 0) {  //set dir pin high, pump to inactive and speed to 1Hz(speed will be ignored later)
              pump_3_active = LOW;
              digitalWrite(DIR_PIN_3, HIGH);
              delay_time_3 = (unsigned long)(1000000);
            }
            else{                       //otherwise set pump to active, dir pin to high, and delay time normally
              pump_3_active = HIGH;
              digitalWrite(DIR_PIN_3, HIGH);
              delay_time_3 = (unsigned long)((float)1000000/(float)read_value);
            }
            
            last_time_3 = micros(); //puts next step time into the future
            Serial.println("value updated!");
          }

          if (Pump4Characteristic.written()) {
            int read_value = Pump4Characteristic.value();
            pump_4_freq.write(read_value);

            //parse read_value
            if (read_value < 0){     //set pump to active, flip sign of read value, and set DIR pin to low
              pump_4_active = HIGH;
              digitalWrite(DIR_PIN_4, LOW);
              delay_time_4 = (unsigned long)((float)1000000/(-(float)read_value));
            }
            else if (read_value == 0) {  //set dir pin high, pump to inactive and speed to 1Hz(speed will be ignored later)
              pump_4_active = LOW;
              digitalWrite(DIR_PIN_4, HIGH);
              delay_time_4 = (unsigned long)(1000000);
            }
            else{                       //otherwise set pump to active, dir pin to high, and delay time normally
              pump_4_active = HIGH;
              digitalWrite(DIR_PIN_4, HIGH);
              delay_time_4 = (unsigned long)((float)1000000/(float)read_value);
            }
            
            last_time_4 = micros(); //puts next step time into the future
            Serial.println("value updated!");
          }

          if (Pump5Characteristic.written()) {
            int read_value = Pump5Characteristic.value();
            pump_5_freq.write(read_value);

            //parse read_value
            if (read_value < 0){     //set pump to active, flip sign of read value, and set DIR pin to low
              pump_5_active = HIGH;
              digitalWrite(DIR_PIN_5, LOW);
              delay_time_5 = (unsigned long)((float)1000000/(-(float)read_value));
            }
            else if (read_value == 0) {  //set dir pin high, pump to inactive and speed to 1Hz(speed will be ignored later)
              pump_5_active = LOW;
              digitalWrite(DIR_PIN_5, HIGH);
              delay_time_5 = (unsigned long)(1000000);
            }
            else{                       //otherwise set pump to active, dir pin to high, and delay time normally
              pump_5_active = HIGH;
              digitalWrite(DIR_PIN_5, HIGH);
              delay_time_5 = (unsigned long)((float)1000000/(float)read_value);
            }
            
            last_time_5 = micros(); //puts next step time into the future
            Serial.println("value updated!");
          }
          
          if (Pump6Characteristic.written()) {
            int read_value = Pump6Characteristic.value();
            pump_6_freq.write(read_value);

            //parse read_value
            if (read_value < 0){     //set pump to active, flip sign of read value, and set DIR pin to low
              pump_6_active = HIGH;
              digitalWrite(DIR_PIN_6, LOW);
              delay_time_6 = (unsigned long)((float)1000000/(-(float)read_value));
            }
            else if (read_value == 0) {  //set dir pin high, pump to inactive and speed to 1Hz(speed will be ignored later)
              pump_6_active = LOW;
              digitalWrite(DIR_PIN_6, HIGH);
              delay_time_6 = (unsigned long)(1000000);
            }
            else{                       //otherwise set pump to active, dir pin to high, and delay time normally
              pump_6_active = HIGH;
              digitalWrite(DIR_PIN_6, HIGH);
              delay_time_6 = (unsigned long)((float)1000000/(float)read_value);
            }
            
            last_time_6 = micros(); //puts next step time into the future
            Serial.println("value updated!");
            
          }
        } 
        current_time = micros();   //update the current time if the BLE code ran to account for any lag
      }
    }
  }

     
  //Checks timers and updates outputs accordingly
  current_time = micros();
  
  if (pump_1_active) {
    if (current_time - last_time_1 >= delay_time_1){
      last_time_1 = current_time;
      pump_1_step = !pump_1_step;               
      digitalWrite(STEP_PIN_1, pump_1_step); 
    }
  }
  if (pump_2_active) {
    if (current_time - last_time_2 >= delay_time_2){
      last_time_2 = current_time;
      pump_2_step = !pump_2_step;              
      digitalWrite(STEP_PIN_2, pump_2_step); 
    }
  }
  if (pump_3_active) {
    if (current_time - last_time_3 >= delay_time_3){
      last_time_3 = current_time;
      pump_3_step = !pump_3_step;              
      digitalWrite(STEP_PIN_3, pump_3_step); 
    }
  }
  if (pump_4_active) {
    if (current_time - last_time_4 >= delay_time_4){
      last_time_4 = current_time;
      pump_4_step = !pump_4_step;               
      digitalWrite(STEP_PIN_4, pump_4_step); 
    }
  }
  if (pump_5_active) {
    if (current_time - last_time_5 >= delay_time_5){
      last_time_5 = current_time;
      pump_5_step = !pump_5_step;               
      digitalWrite(STEP_PIN_5, pump_5_step); 
    }
  }
  if (pump_6_active) {
    if (current_time - last_time_6 >= delay_time_6){
      last_time_6 = current_time;
      pump_6_step = !pump_6_step;               
      digitalWrite(STEP_PIN_6, pump_6_step); 
    }
  }
}

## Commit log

2024-05-21 Uploaded Files
    First content
    [Starter Docking Plate Bottom layer.SLDPRT, Starter Docking Plate Bottom layer.STL, Starter Docking Plate Top layer.SLDPRT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]
2024-06-08 Added design files
    [30x15 Reservoir-3x_v1.03.SLDPRT, 30x15 Reservoir-3x_v1.03.STL]
2024-10-23 Fixed bug when updating BLE displayed frequency on reboot in Pump_Module_Firmware.ino
    [Pump_Module_Firmware.ino]
2024-11-06 Delete FCB/Starter Docking Plate Top layer.SLDPRT
    Removed to upgrade later
    [Starter Docking Plate Top layer.SLDPRT]
2024-11-06 Delete FCB/Starter Docking Plate Bottom layer.SLDPRT
    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
    [Starter Docking Plate Bottom layer.SLDPRT]
2026-04-15 Update Pump_Module_Firmware.ino
    Reduce frequency of BLE update checks.
2026-04-17 Update Pump_Module_Firmware.ino
    Removed extra calls to calls to micros() and added faster checking for connected BLE devices.
2026-05-06 Fixed error with BLE timer update and moved the BLE connection check out of the mail loop.
    [Pump_Module_Firmware.ino]
2026-05-06 Included reference to Arduino firmware update

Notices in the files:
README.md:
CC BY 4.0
